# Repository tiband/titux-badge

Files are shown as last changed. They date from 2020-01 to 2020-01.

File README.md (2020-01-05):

# TiTux badge

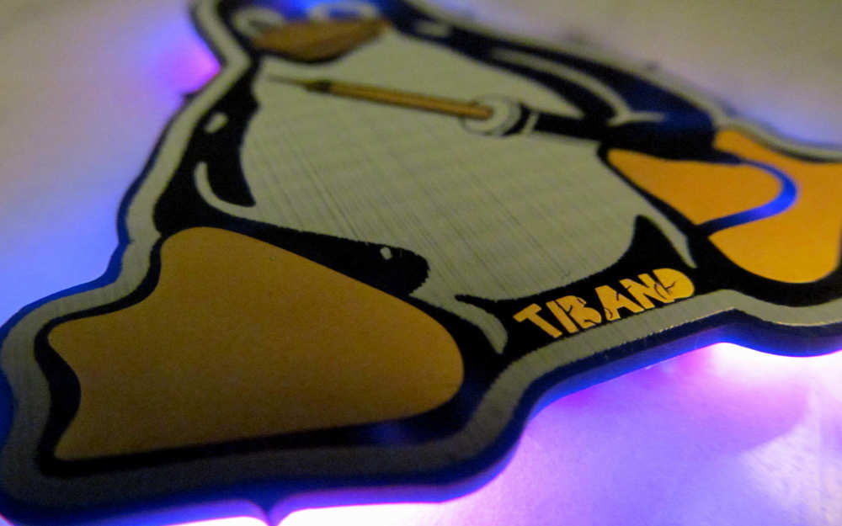
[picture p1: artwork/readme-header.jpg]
TiTux badge


## board

The board is designed in KiCad and uses a dual sided pcb while only using one side for the components. It features an ATtiny84 with 6 LEDs and a switch powered by a 3 V button cell. The example above was manufactured by [OSH Park].

## code

The challenge is to come up with your own interesting light shows, games, etc. for the badge. This repo includes a basic Arduino sketch using the [ATTinyCore] to get you started.

Use some crocodile clips and an AVR ISP programmer like a standard Arduino UNO with the [ISP sketch] and a 10 μF capacitor.

## licence

The design and example firmware are licenced under `GPL-3.0-or-later`.

[OSH Park]: https://oshpark.com/
[ATTinyCore]: https://github.com/SpenceKonde/ATTinyCore
[ISP sketch]: https://www.arduino.cc/en/tutorial/arduinoISP

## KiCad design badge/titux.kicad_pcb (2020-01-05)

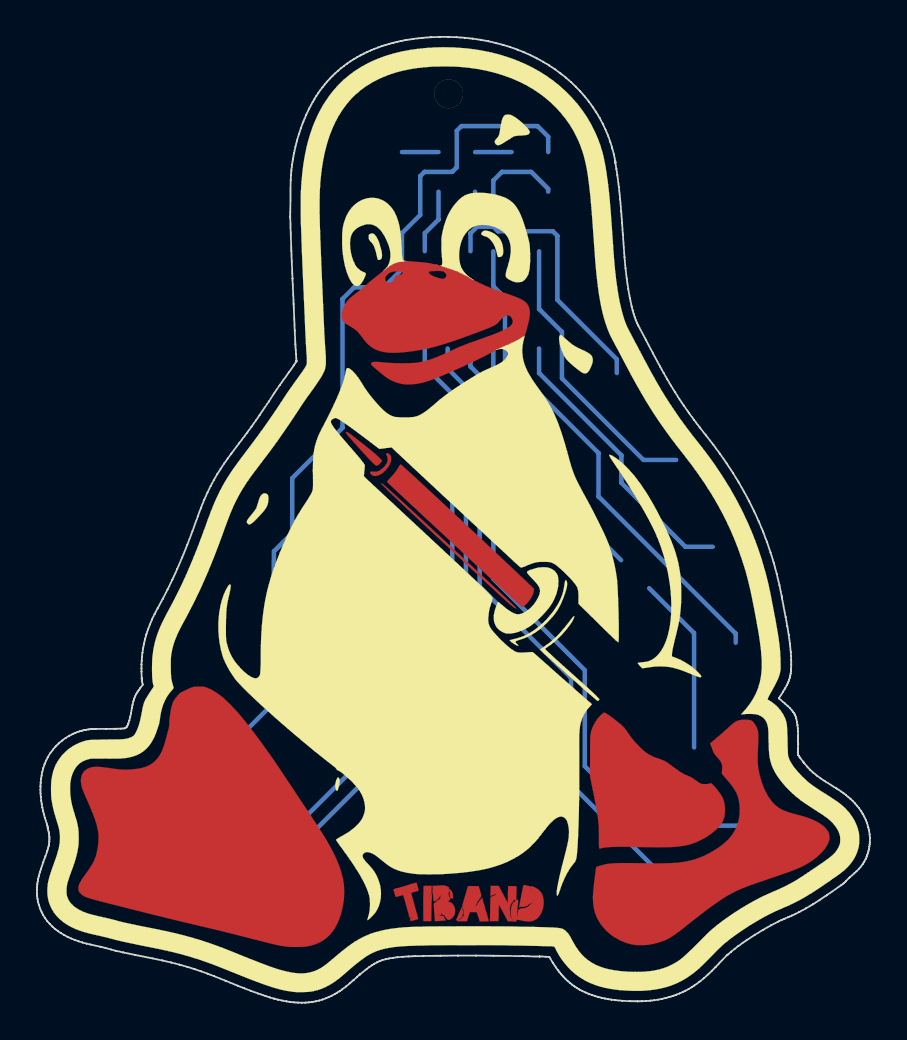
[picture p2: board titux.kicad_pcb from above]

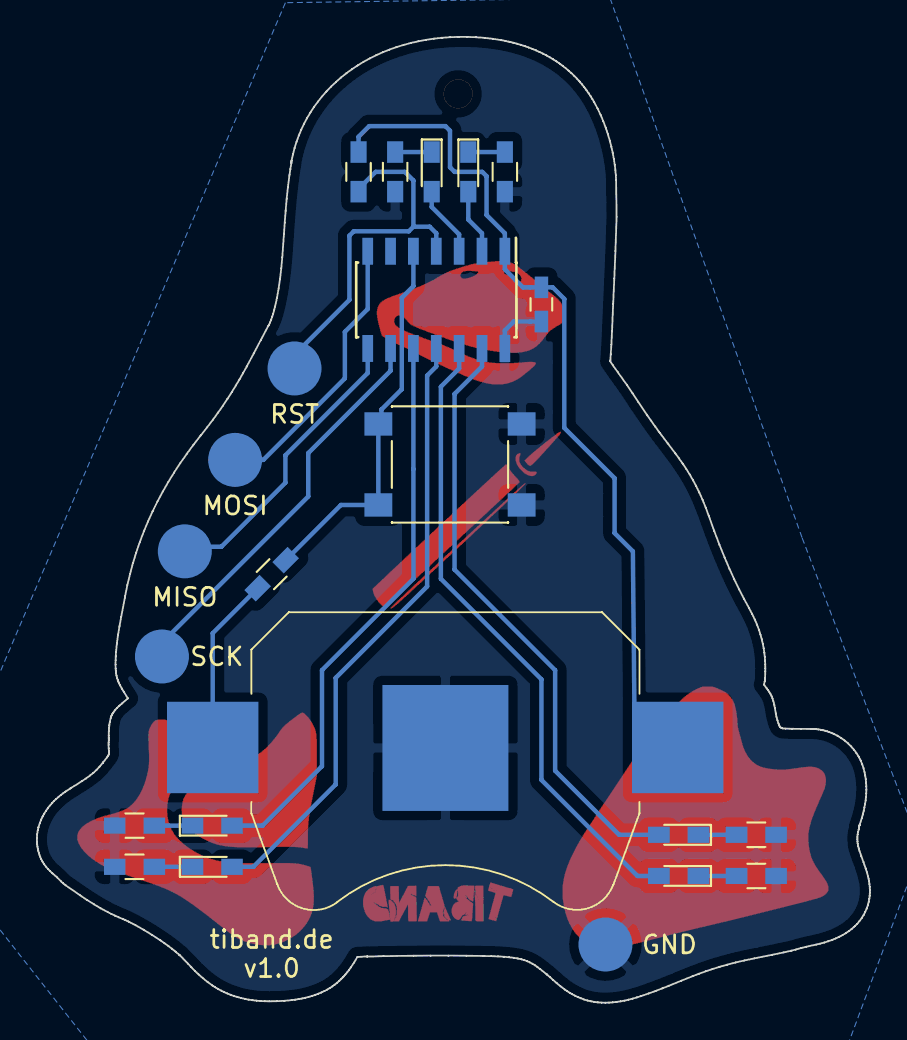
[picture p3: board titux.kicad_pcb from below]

Board: 2 copper layers, 46.3 x 53.7 mm, 23 parts (23 on the bottom side), 19 nets.

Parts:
BT1: Battery_Cell; KZH_20SMD_1x20mm-CoinCell
C1: 100n; C_0603_HandSoldering
D1, D2, D3, D4, D5, D6: LED_Small; LED_0603_HandSoldering
GND: Conn_01x01; KrokoPad
MISO: Conn_01x01; KrokoPad
MOSI: Conn_01x01; KrokoPad
R1, R2, R3, R4, R5, R6: R_Small; R_0603_HandSoldering
R10, R11: 10k; R_0603_HandSoldering
RST: Conn_01x01; KrokoPad
SCK: Conn_01x01; KrokoPad
SW1: SW_Push; Switch_SMD_rotated_6x6x4,3
U1: ATtiny84A-SSU; SOIC-14_3.9x8.7mm_Pitch1.27mm

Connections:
/LED_B1: D1.2, U1.12
/LED_B2: D3.2, U1.10
/LED_B3: D5.2, U1.3
/LED_R1: D2.2, U1.13
/LED_R2: D4.2, U1.11
/LED_R3: D6.2, U1.2
/MISO: MISO.1, U1.8
/MOSI: MOSI.1, U1.7
/RESET: R11.2, RST.1, U1.4
/SCK: SCK.1, U1.9
GND: BT1.2, C1.2, GND.1, R1.2, R2.2, R3.2, R4.2, R5.2, R6.2, SW1.1, U1.14
unnamed: D1.1, R1.1
unnamed: D2.1, R2.1
unnamed: D3.1, R3.1
unnamed: D4.1, R4.1
unnamed: D5.1, R5.1
unnamed: D6.1, R6.1
unnamed: R10.2, SW1.2, U1.5
VCC: BT1.1, C1.1, R10.1, R11.1, U1.1

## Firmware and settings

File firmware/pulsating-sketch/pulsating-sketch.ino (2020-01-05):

const uint16_t PWM_MAX_VALUE = 128;
const uint16_t PWM_CYCLE = 30; // us

// digitalWrite is too slow…
inline void set_pin(uint8_t pin) {
  if(pin < 8) {
    PORTA |= 1 << pin;
  } else {
    PORTB |= 1 << (10 - pin);
  }
}
inline void reset_pin(uint8_t pin) {
  if(pin < 8) {
    PORTA &= ~(1 << pin);
  } else {
    PORTB &= ~(1 << (10 - pin));
  }
}

struct PwmPin {
  uint8_t location;
  uint16_t value;
  uint16_t tick;
};

enum Leds {
  LED_LEFT_R,
  LED_LEFT_B,
  LED_RIGHT_R,
  LED_RIGHT_B,
  LED_TOP_R,
  LED_TOP_B,
};

PwmPin pins[] = {
  { 0, 20, 0},
  { 1, 20, 0},
  { 2, 10, 0},
  { 3, 10, 0},
  {10, 5, 0},
  { 9, 5, 0},
};

unsigned long last_micros = 0;
void pwm_tick() {
  if(micros() - last_micros > PWM_CYCLE) {
    for(auto& pin : pins) {
      if(pin.tick < pin.value) {
        set_pin(pin.location);
      } else {
        reset_pin(pin.location);
      }

      pin.tick = (pin.tick + 1) % PWM_MAX_VALUE;
    }

    last_micros = micros();
  }
}

void setup() {
  for(auto& pin : pins) {
    pinMode(pin.location, OUTPUT);
  }
}


struct FadeStep {
  uint16_t target;
  uint16_t step_width;
};

FadeStep pulsating_pattern_top[] = {
   {21, 1},
   {2, 1},
   {0, 0},
};
FadeStep pulsating_pattern_left[] = {
   {35, 1},
   {6, 1},
   {0, 0},
};
FadeStep pulsating_pattern_right[] = {
   {40, 1},
   {9, 1},
   {0, 0},
};

struct PatternState {
  uint8_t pin;
  FadeStep* pattern_start;
  FadeStep* pattern_current;
};

PatternState patterns[] = {
  {LED_TOP_R, pulsating_pattern_top, pulsating_pattern_top},
  {LED_TOP_B, pulsating_pattern_top, pulsating_pattern_top},
  {LED_LEFT_R, pulsating_pattern_left, pulsating_pattern_left},
  {LED_LEFT_B, pulsating_pattern_left, pulsating_pattern_left},
  {LED_RIGHT_R, pulsating_pattern_right, pulsating_pattern_right},
  {LED_RIGHT_B, pulsating_pattern_right, pulsating_pattern_right},
};

unsigned long last_millis = 0;
void loop() {
  pwm_tick();

  if(millis() - last_millis > 100) {
    for(auto& pattern : patterns) {
      if(pins[pattern.pin].value > pattern.pattern_current->target) {
        pins[pattern.pin].value = max(pins[pattern.pin].value - pattern.pattern_current->step_width, pattern.pattern_current->target);
      } else if(pins[pattern.pin].value < pattern.pattern_current->target) {
        pins[pattern.pin].value = min(pins[pattern.pin].value + pattern.pattern_current->step_width, pattern.pattern_current->target);
      }

      if(pins[pattern.pin].value == pattern.pattern_current->target) {
        pattern.pattern_current = pattern.pattern_current + 1;
        if(pattern.pattern_current->step_width == 0) {
          pattern.pattern_current = pattern.pattern_start;
        }
      }
    }

    last_millis = millis();
  }
}

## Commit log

2020-01-05 Import version 1.0 of the board layout
    [titux.kicad_pcb, titux.sch]
2020-01-05 Add simple example firmware for pulsating the leds
